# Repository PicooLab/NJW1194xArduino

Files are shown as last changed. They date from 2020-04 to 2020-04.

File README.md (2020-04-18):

# NJW1194 x Arduino

2-Channel Electronic Volume With Input Selector And Tone Control

Designed with Kicad and Arduino IDE;

## Related

+ NJW1194
  <https://www.njr.com/semicon/products/NJW1194.html>
  [Datasheet](assets/NJW1194_E.pdf)
+ Arduino Nano
  <https://store.arduino.cc/usa/arduino-nano>
+ 1602_I2C Screen
  <https://github.com/mathertel/LiquidCrystal_PCF8574>
+ EC11 Ratary Encoder
  <https://tech.alpsalpine.com/prod/e/html/encoder/incremental/ec11/ec11_list.html>

## Hardware

### 1. NJW1194 board

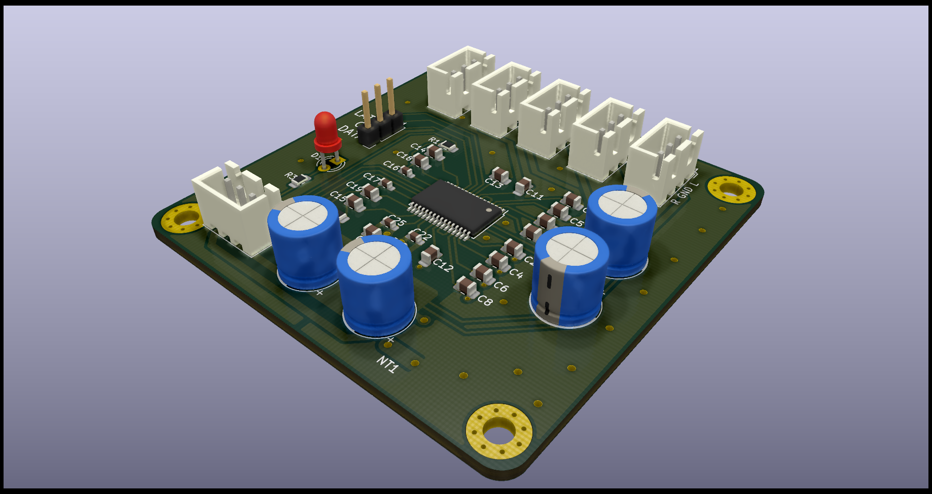
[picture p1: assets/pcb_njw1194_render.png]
NJW1194


Size : 60mmx60mm

### 2. POWER board

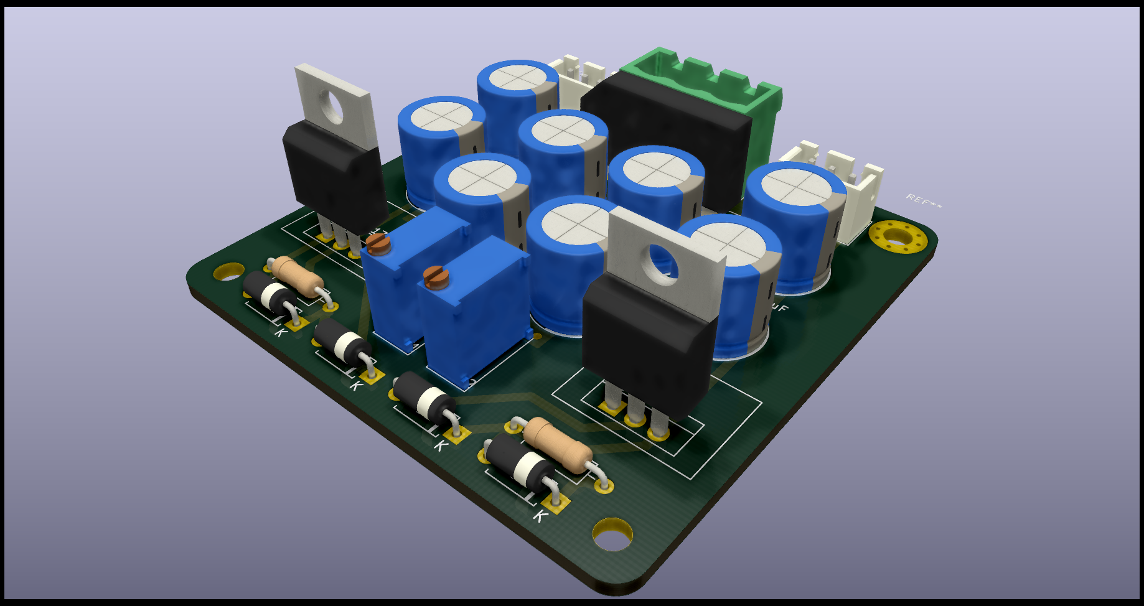
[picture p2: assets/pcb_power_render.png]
POWER


Size : 60mmx60mm

### 3. CONTROL board

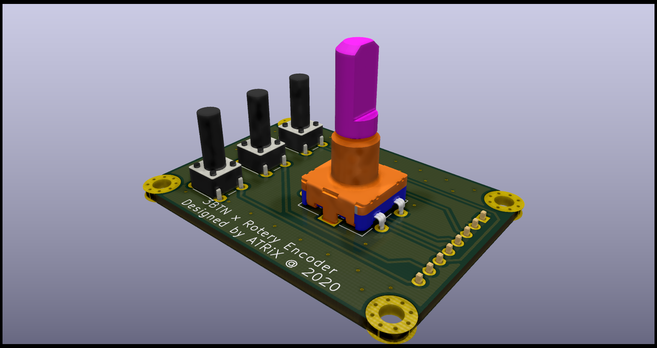
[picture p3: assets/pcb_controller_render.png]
CONTROL


Size : 36mmx50mm

## Software

[Arduino nano](nano_eeprom_bal/nano_eeprom_bal.ino)

not elegant enough yet

## Assemble

TBD...

## MIT License

Copyright (c) 2020 ATRiiX

Permission is hereby granted, free of charge, to any person obtaining a copy
of this software and associated documentation files (the "Software"), to deal
in the Software without restriction, including without limitation the rights
to use, copy, modify, merge, publish, distribute, sublicense, and/or sell
copies of the Software, and to permit persons to whom the Software is
furnished to do so, subject to the following conditions:

The above copyright notice and this permission notice shall be included in all
copies or substantial portions of the Software.

THE SOFTWARE IS PROVIDED "AS IS", WITHOUT WARRANTY OF ANY KIND, EXPRESS OR
IMPLIED, INCLUDING BUT NOT LIMITED TO THE WARRANTIES OF MERCHANTABILITY,
FITNESS FOR A PARTICULAR PURPOSE AND NONINFRINGEMENT. IN NO EVENT SHALL THE
AUTHORS OR COPYRIGHT HOLDERS BE LIABLE FOR ANY CLAIM, DAMAGES OR OTHER
LIABILITY, WHETHER IN AN ACTION OF CONTRACT, TORT OR OTHERWISE, ARISING FROM,
OUT OF OR IN CONNECTION WITH THE SOFTWARE OR THE USE OR OTHER DEALINGS IN THE
SOFTWARE.

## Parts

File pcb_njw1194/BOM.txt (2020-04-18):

BOM of NJW1194

J1;                   PinHeader_P2.54mm_3P;   1;
J2-J7;                JST_XH2.54mm_3P;        6;

U1;                   SSOP-32;                1;    NJW1194;

R1,R2;                R_0805;                 2;    4.7K;
R3;                   R_0805;                 1;    1k-1.5k;
D1;                   LED_D3.0mm;             1;

C9,C10,C20,C23;       CP_D8mm_P3.5mm;         2;    100uF;
C16,C17,C22,C25;      C_0603";                4;    100nf;
C1-C8,C11-13,C21,C24; C_0805";               13;    10uf;
C14,C15;              C_0805";                2;    3.3nf;
C18,C19;              C_0805";                2;    4.7uf;

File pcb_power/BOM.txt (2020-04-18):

BOM of LM317x337

J1;                  "5.08mm_3P";        1;
J2,J3;               "XH2.54_3P";        2;

U1;                  "TO-220";           1;    LM317;
U2;                  "TO-220";           1;    LM337;

R1,R2;               "R1/4W";            2;    100;
RV2,RV1;             "3296W";            2;    1K;
D1";                 "Diode_Bridge";     1;    D_Bridge_+AA-;
D2-D5;               "4N7001";           4;

C14,C13,C8,C7,C1-C4; "CP_D10mm_P5mm";    8;    1000u;
C12,C11,C6,C5;       "C_0603;            4;    100nf
C10,C9;              "C_0805";           2;    10uf;

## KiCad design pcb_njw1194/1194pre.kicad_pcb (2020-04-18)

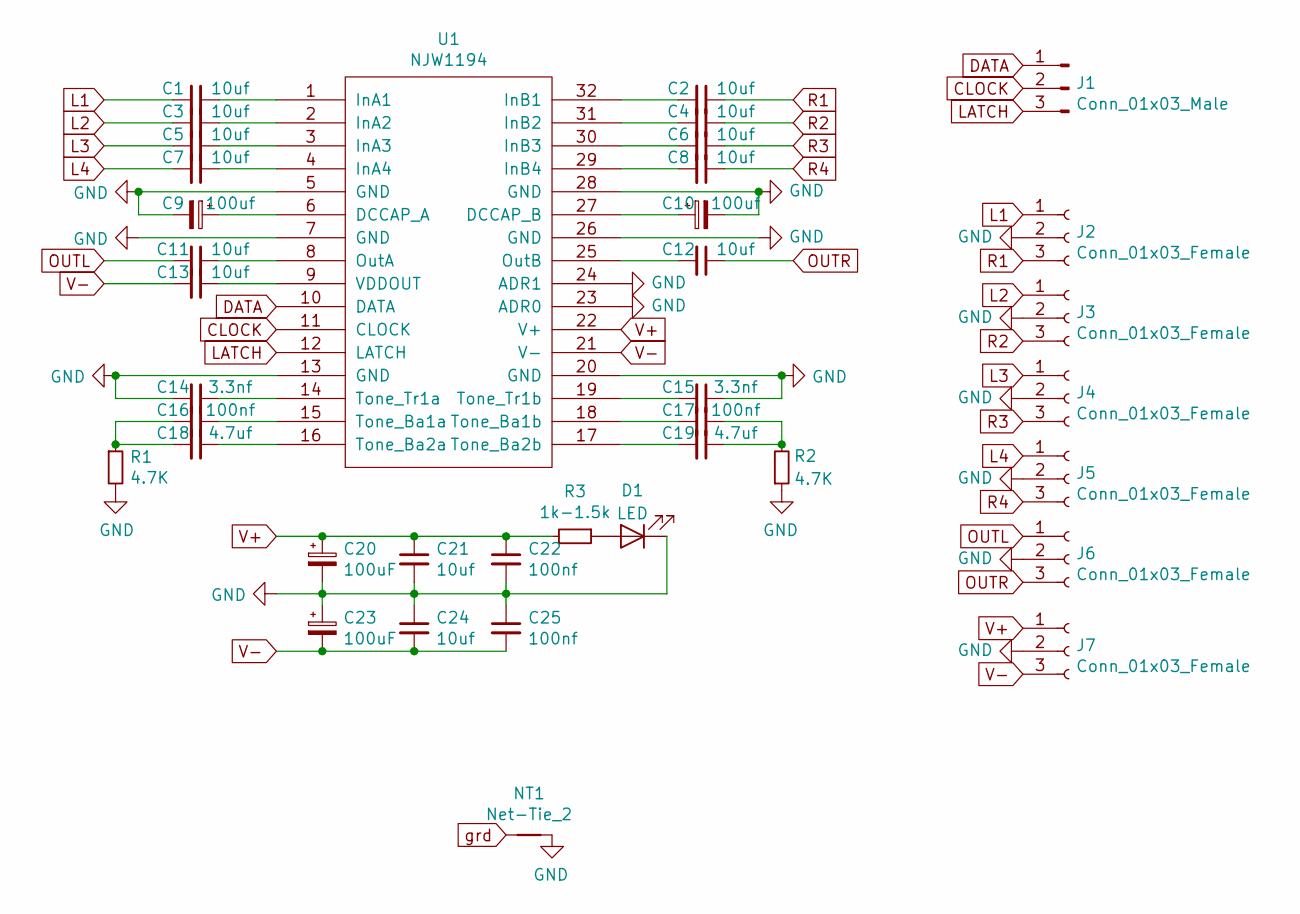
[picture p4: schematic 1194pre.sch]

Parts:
C1, C2, C3, C4, C5, C6, C7, C8, C11, C12, C13, C21, C24: 10uf; C_0805_2012Metric_Pad1.15x1.40mm_HandSolder
C9, C10: 100uf; CP_Radial_D8.0mm_P3.50mm
C14, C15: 3.3nf; C_0805_2012Metric_Pad1.15x1.40mm_HandSolder
C16, C17, C22, C25: 100nf; C_0603_1608Metric_Pad1.05x0.95mm_HandSolder
C18, C19: 4.7uf; C_0805_2012Metric_Pad1.15x1.40mm_HandSolder
C20, C23: 100uF; CP_Radial_D8.0mm_P3.50mm
D1: LED; LED_D3.0mm
J1: Conn_01x03_Male; PinHeader_1x03_P2.54mm_Vertical
J2, J3, J4, J5, J6, J7: Conn_01x03_Female; JST_XH_B3B-XH-A_1x03_P2.50mm_Vertical
NT1: Net-Tie_2; NetTie-2_SMD_Pad2.0mm
R1, R2: 4.7K; R_0805_2012Metric_Pad1.15x1.40mm_HandSolder
R3: 1k-1.5k; R_0805_2012Metric_Pad1.15x1.40mm_HandSolder
U1: NJW1194; TSSOP-32_6.1x11mm_P0.65mm

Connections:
CLOCK: J1.2, U1.11 (CLOCK)
DATA: J1.1, U1.10 (DATA)
GND: C9.2, C10.2, C14.2, C15.1, C20.2, C21.2, C22.2, C23.1, C24.1, C25.1, D1.1 (K), J2.2, J3.2, J4.2, J5.2, J6.2, J7.2, NT1.2, R1.2, R2.1, U1.5 (GND), U1.7 (GND), U1.13 (GND), U1.20 (GND), U1.23 (ADR0), U1.24 (ADR1), U1.26 (GND), U1.28 (GND)
L1: C1.2, J2.1
L2: C3.2, J3.1
L3: C5.2, J4.1
L4: C7.2, J5.1
LATCH: J1.3, U1.12 (LATCH)
unnamed: C1.1, U1.1 (InA1)
unnamed: C2.2, U1.32 (InB1)
unnamed: C3.1, U1.2 (InA2)
unnamed: C4.2, U1.31 (InB2)
unnamed: C5.1, U1.3 (InA3)
unnamed: C6.2, U1.30 (InB3)
unnamed: C7.1, U1.4 (InA4)
unnamed: C8.2, U1.29 (InB4)
unnamed: C9.1, U1.6 (DCCAP_A)
unnamed: C10.1, U1.27 (DCCAP_B)
unnamed: C11.1, U1.8 (OutA)
unnamed: C12.2, U1.25 (OutB)
unnamed: C13.1, U1.9 (VDDOUT)
unnamed: C14.1, U1.14 (Tone_Tr1a)
unnamed: C15.2, U1.19 (Tone_Tr1b)
unnamed: C16.1, U1.15 (Tone_Ba1a)
unnamed: C16.2, C18.2, R1.1
unnamed: C17.1, C19.1, R2.2
unnamed: C17.2, U1.18 (Tone_Ba1b)
unnamed: C18.1, U1.16 (Tone_Ba2a)
unnamed: C19.2, U1.17 (Tone_Ba2b)
unnamed: D1.2 (A), R3.1
OUTL: C11.2, J6.1
OUTR: C12.1, J6.3
R1: C2.1, J2.3
R2: C4.1, J3.3
R3: C6.1, J4.3
R4: C8.1, J5.3
V+: C20.1, C21.1, C22.1, J7.1, R3.2, U1.22 (V+)
V-: C13.2, C23.2, C24.2, C25.2, J7.3, U1.21 (V-)
grd: NT1.1

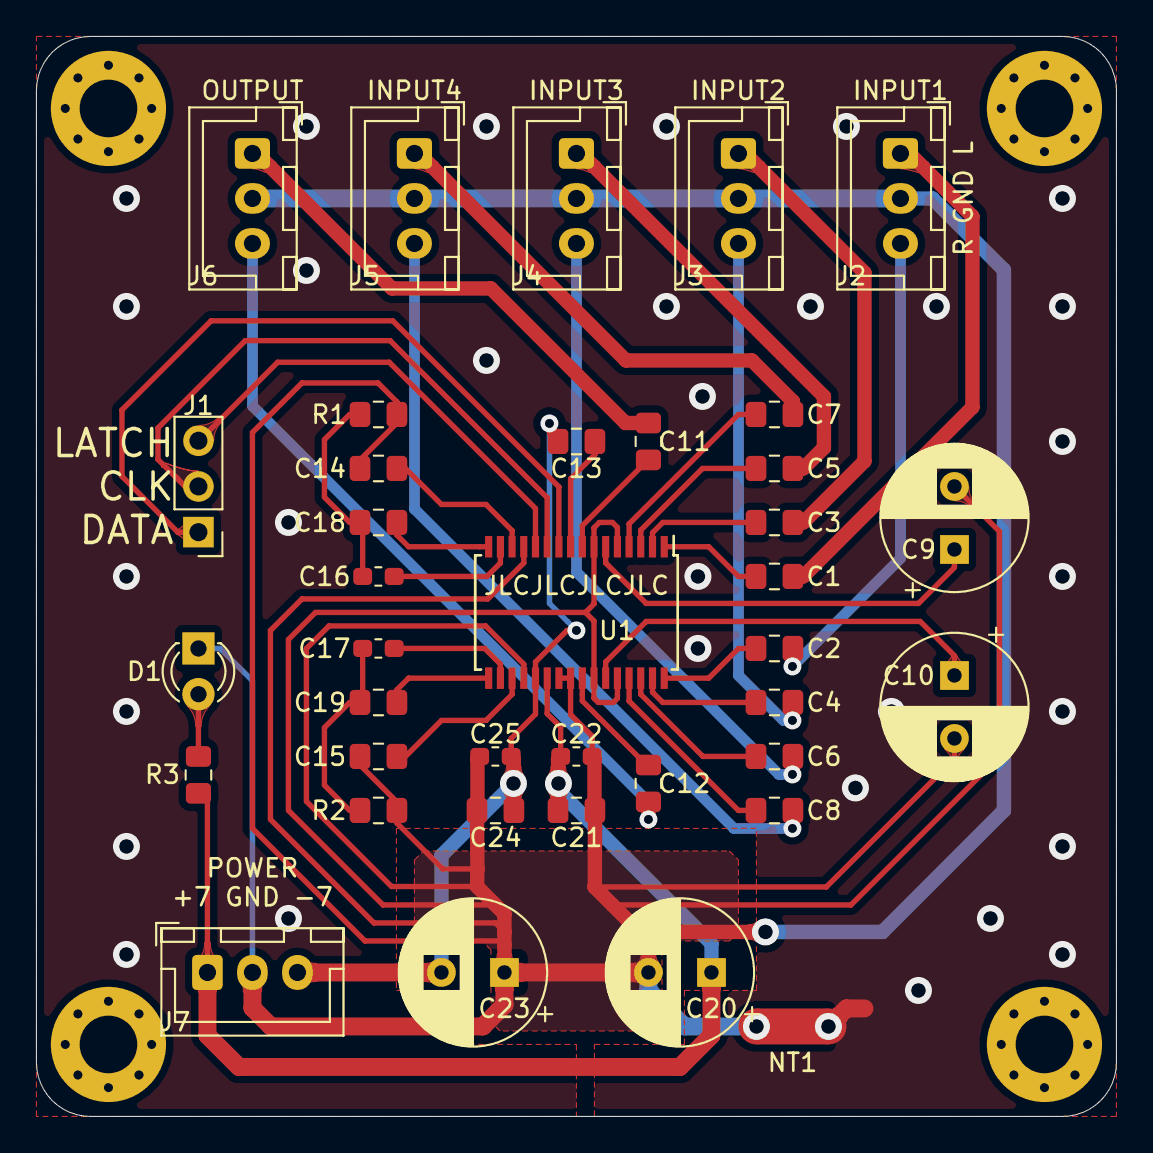
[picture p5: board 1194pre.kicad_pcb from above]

Board: 2 copper layers, 60.0 x 60.0 mm, 38 parts (0 on the bottom side), 38 nets.

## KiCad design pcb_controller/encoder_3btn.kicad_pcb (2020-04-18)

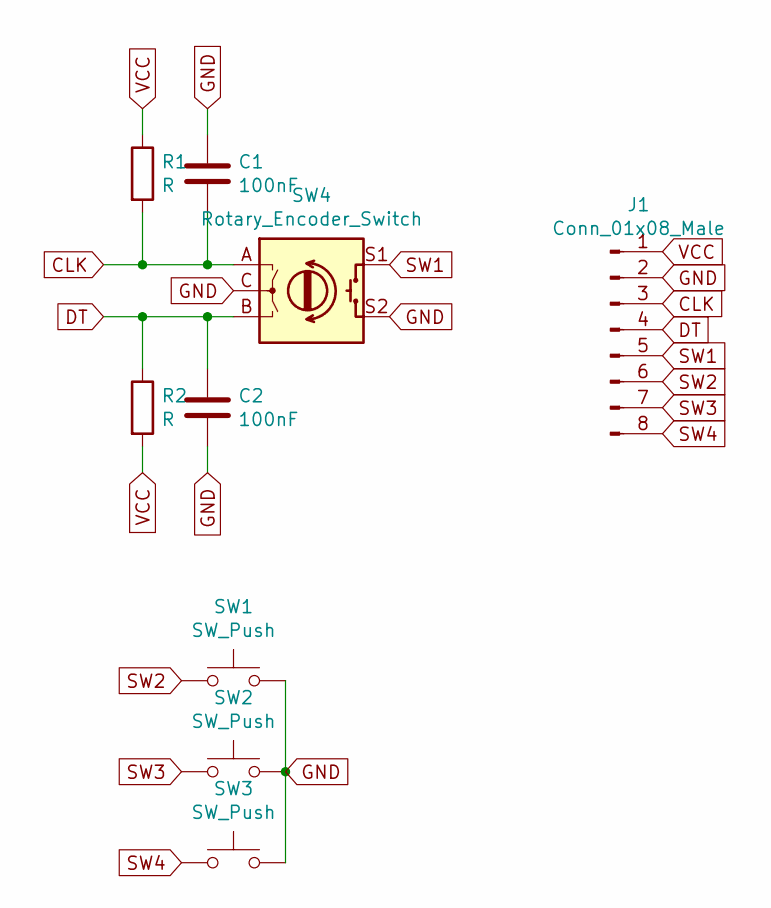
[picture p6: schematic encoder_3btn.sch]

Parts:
C1, C2: 100nF; C_0603_1608Metric_Pad1.05x0.95mm_HandSolder
J1: Conn_01x08_Male; PinHeader_1x08_P2.54mm_Horizontal
R1, R2: R; R_0805_2012Metric_Pad1.15x1.40mm_HandSolder
SW1, SW2, SW3: SW_Push; SW_PUSH_6mm_H13mm
SW4: Rotary_Encoder_Switch; RotaryEncoder_Alps_EC11E-Switch_Vertical_H20mm

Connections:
CLK: C1.2, J1.3, R1.2, SW4.A
DT: C2.1, J1.4, R2.1, SW4.B
GND: C1.1, C2.2, J1.2, SW1.2, SW2.2, SW3.2, SW4.C, SW4.S2
SW1: J1.5, SW4.S1
SW2: J1.6, SW1.1
SW3: J1.7, SW2.1
SW4: J1.8, SW3.1
VCC: J1.1, R1.1, R2.2

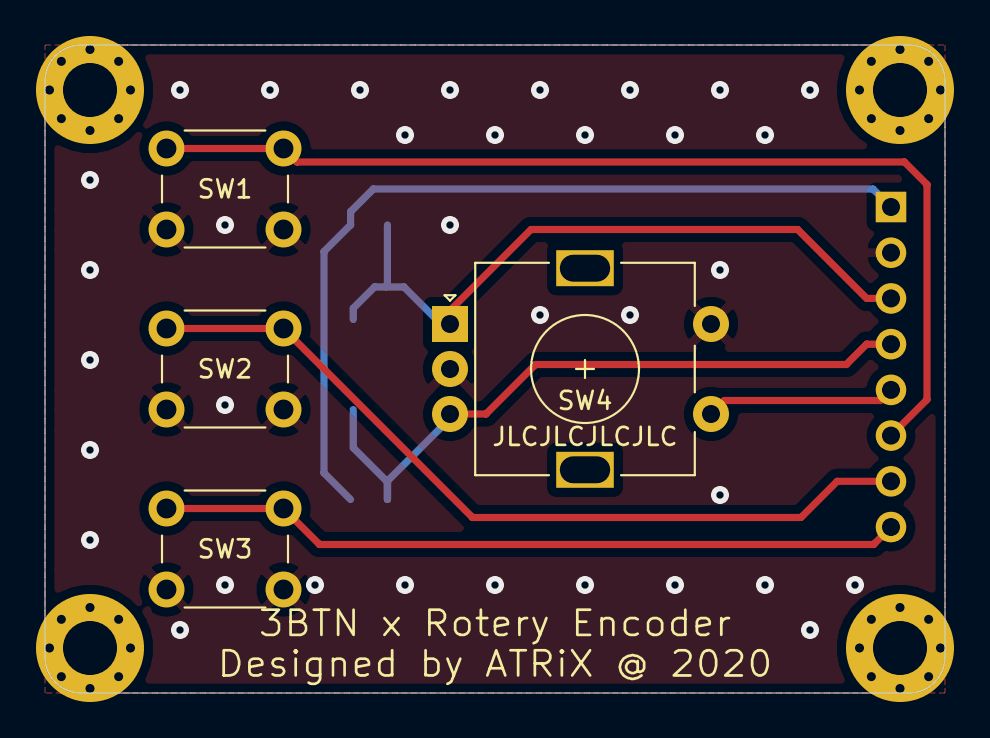
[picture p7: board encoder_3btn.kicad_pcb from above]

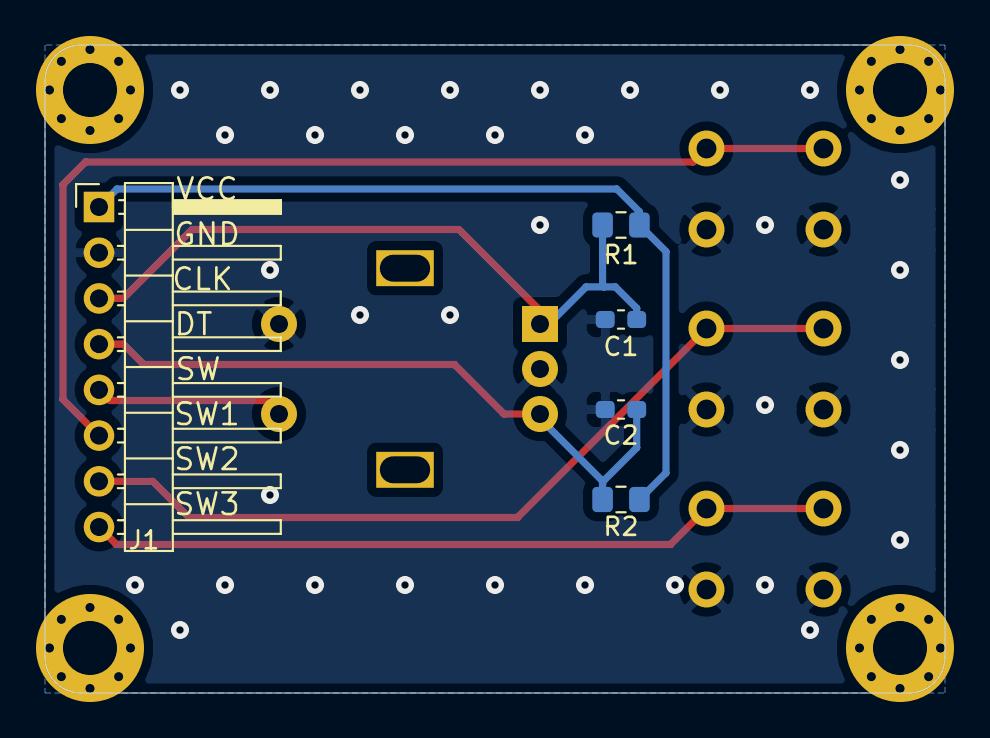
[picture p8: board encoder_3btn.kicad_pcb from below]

Board: 2 copper layers, 50.0 x 36.0 mm, 13 parts (5 on the bottom side), 8 nets.

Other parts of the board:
REF1, REF2, REF3, REF4: MountingHole_3mm_Pad_Via

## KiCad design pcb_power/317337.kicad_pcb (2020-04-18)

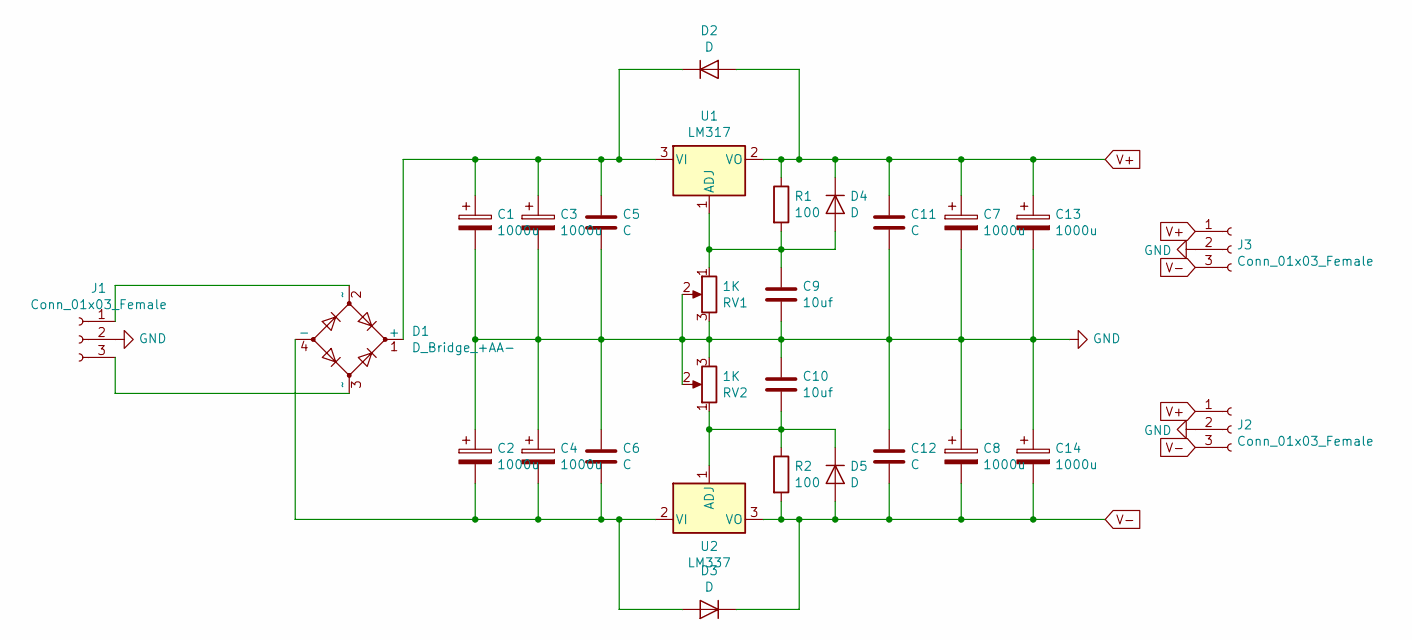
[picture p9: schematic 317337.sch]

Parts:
C1, C2, C3, C4, C7, C8, C13, C14: 1000u; CP_Radial_D10.0mm_P5.00mm
C5, C6, C11, C12: C; C_0603_1608Metric_Pad1.05x0.95mm_HandSolder
C9, C10: 10uf; C_0805_2012Metric_Pad1.15x1.40mm_HandSolder
D1: D_Bridge_+AA-; Diode_Bridge_Vishay_GBL
D2, D3, D4, D5: D; D_A-405_P7.62mm_Horizontal
J1: Conn_01x03_Female; PhoenixContact_MSTBVA_2,5_3-G-5,08_1x03_P5.08mm_Vertical
J2, J3: Conn_01x03_Female; JST_XH_B3B-XH-A_1x03_P2.50mm_Vertical
R1, R2: 100; R_Axial_DIN0207_L6.3mm_D2.5mm_P10.16mm_Horizontal
RV1, RV2: 1K; Potentiometer_Bourns_3296W_Vertical
U1: LM317; TO-220-3_Vertical
U2: LM337; TO-220-3_Vertical

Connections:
GND: C1.2, C2.1, C3.2, C4.1, C5.2, C6.1, C7.2, C8.1, C9.2, C10.1, C11.2, C12.1, C13.2, C14.1, J1.2, J2.2, J3.2, RV1.2, RV1.3, RV2.2, RV2.3
unnamed: C1.1, C3.1, C5.1, D1.1 (+), D2.1 (K), U1.3 (VI)
unnamed: C2.2, C4.2, C6.2, D1.4 (-), D3.2 (A), U2.2 (VI)
unnamed: C9.1, D4.2 (A), R1.2, RV1.1, U1.1 (ADJ)
unnamed: C10.2, D5.1 (K), R2.1, RV2.1, U2.1 (ADJ)
unnamed: D1.2 (~~), J1.1
unnamed: D1.3 (~~), J1.3
V+: C7.1, C11.1, C13.1, D2.2 (A), D4.1 (K), J2.1, J3.1, R1.1, U1.2 (VO)
V-: C8.2, C12.2, C14.2, D3.1 (K), D5.2 (A), J2.3, J3.3, R2.2, U2.3 (VO)

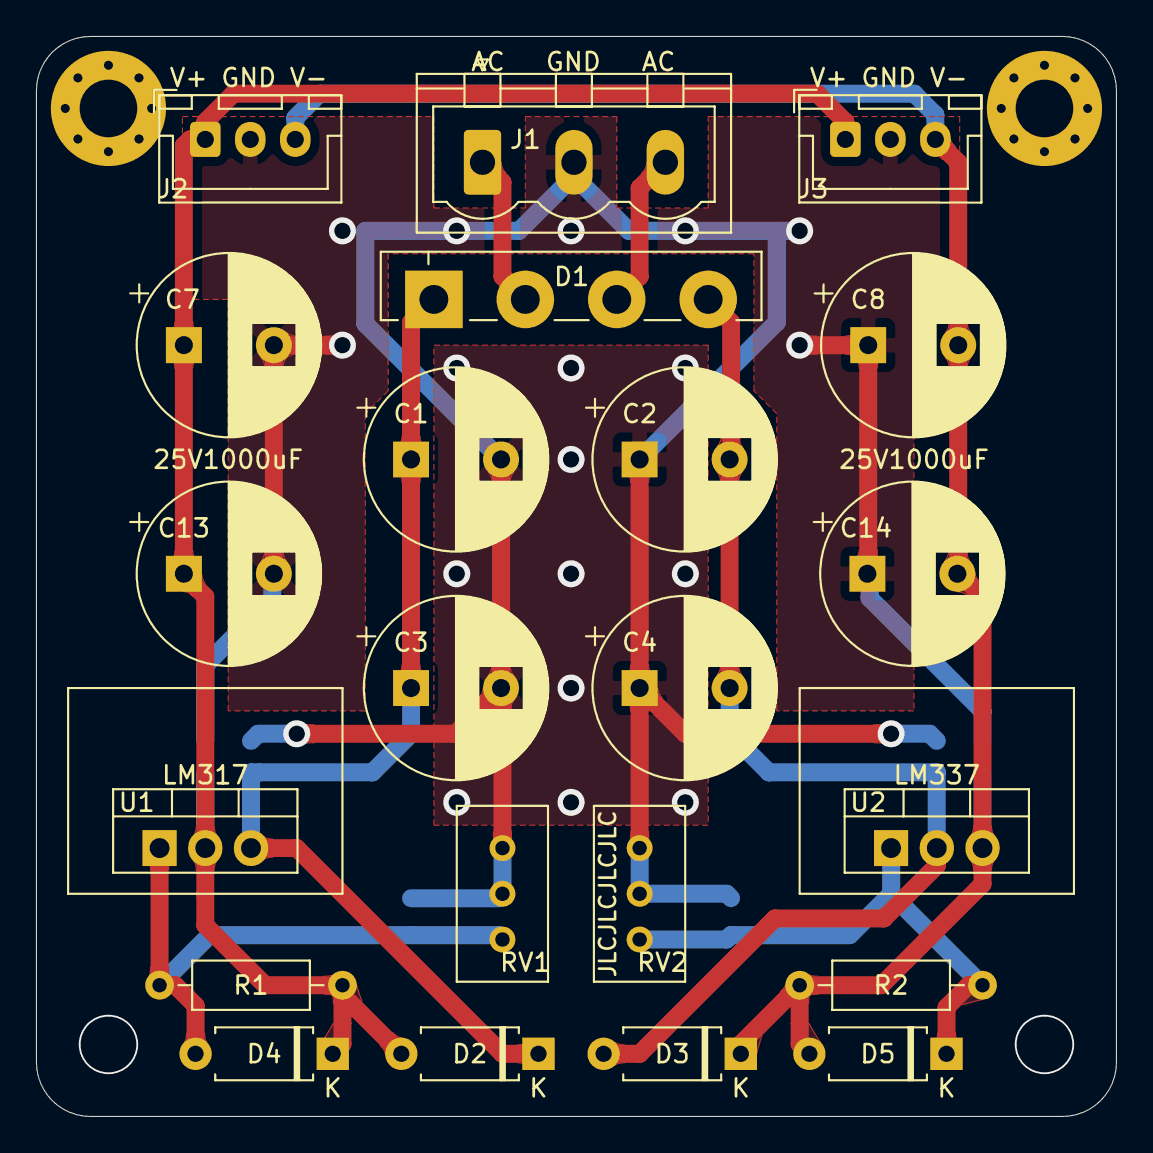
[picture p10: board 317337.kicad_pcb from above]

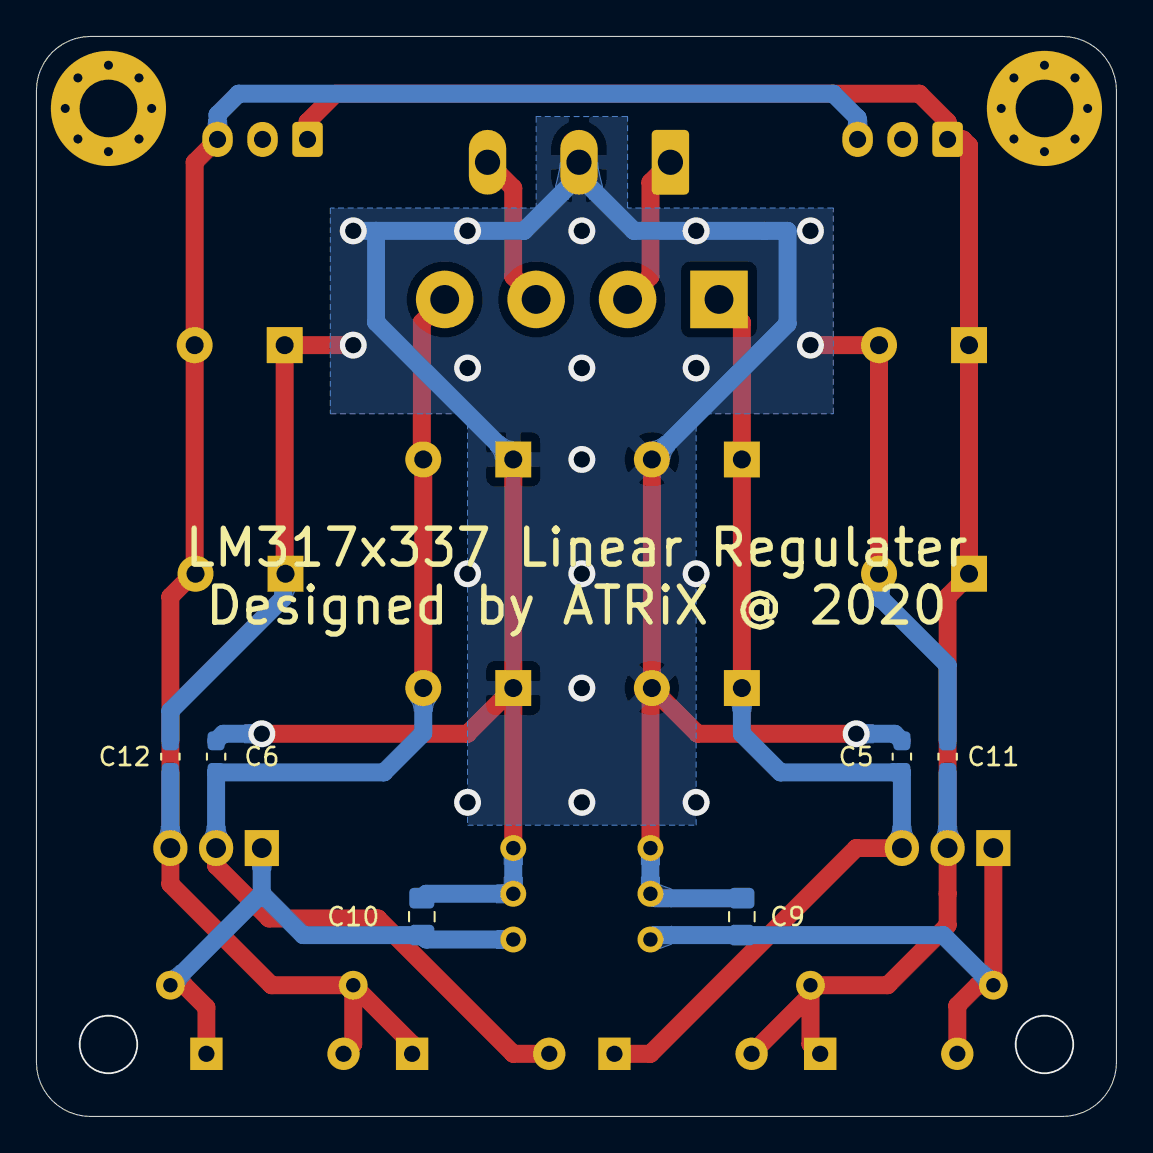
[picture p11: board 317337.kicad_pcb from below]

Board: 2 copper layers, 60.0 x 60.0 mm, 28 parts (6 on the bottom side), 9 nets.

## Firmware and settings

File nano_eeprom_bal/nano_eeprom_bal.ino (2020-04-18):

#include <LiquidCrystal_PCF8574.h>
#include <EEPROM.h>
#include <Wire.h>

LiquidCrystal_PCF8574 lcd(0x27); // set the LCD address to 0x27 for a 16 chars and 2 line display

//NANO EEPROM
//each byte hold a value from 0 to 255
#define EEPROM_CHANNEL 0 //1 to 4
#define EEPROM_MUTE 1    //0 or 1
#define EEPROM_VOLUME 2  //1 to 254  <-> 31.5dB to -95dB,default = 64
#define EEPROM_BALANCE 3 //0 to 80   <-> -20dB to 20dB,  default = 40
#define EEPROM_BYPASS 4  //0 or 1
#define EEPROM_TREBLE 5  //0 to 20   <-> -10dB to 10dB,  default = 10
#define EEPROM_BASS 6    //0 to 20   <-> -10dB to 10dB

//NANO GPIO
//pin keys
#define PIN_CHANNEL 9
#define PIN_MUTE 8
#define PIN_UP 7
#define PIN_DOWN 6
#define PIN_SELECT 5 //Volume,Treble,Bass,Balance
#define PIN_BYPASS 4
//pin njw1194
#define PIN_LATCH A1
#define PIN_CLK A2
#define PIN_DATA A3
//pin rotary encoder
#define PIN_CLK2 10
#define PIN_DT 11

//
#define PINBTN(pinname)    \
  pinMode(pinname, INPUT); \
  digitalWrite(pinname, HIGH);

//
#define BTN_EVENT(pinname, pinx, event, longpush)               \
  static boolean lock_##pinname = false;                        \
  static int count_##pinname = 0;                               \
  if (digitalRead(pinx) == LOW && lock_##pinname == false)      \
  {                                                             \
    lock_##pinname = true;                                      \
    count_##pinname = 0;                                        \
    event();                                                    \
    evt_btn_common();                                           \
  }                                                             \
  else if (digitalRead(pinx) == HIGH && lock_##pinname == true) \
  {                                                             \
    lock_##pinname = false;                                     \
  }                                                             \
  else if (digitalRead(pinx) == LOW && longpush)                \
  {                                                             \
    if (count_##pinname < 500)                                  \
      count_##pinname++;                                        \
    else                                                        \
    {                                                           \
      event();                                                  \
      evt_btn_common();                                         \
    }                                                           \
  }

//
struct Config
{
  byte channel, mute, volume, balance, bypass, treble, bass;
};

Config myConfig = {0, 1, 64, 40, 0, 10, 10};

byte select = 0; //0:Vol,1:Tre,2:Bass,3:Bal;

void evt_btn_ch()
{
  myConfig.channel = (myConfig.channel + 1) % 4;
}
void evt_btn_mu()
{
  if (myConfig.mute == 0)
  {
    myConfig.mute = 1;
  }
  else
  {
    myConfig.mute = 0;
  }
}
void evt_btn_vu()
{
  switch (select)
  {
  case 0:
    if (myConfig.volume >= 4 && myConfig.volume <= 32)
      myConfig.volume -= 2; //16 to 31
    if (myConfig.volume >= 33 && myConfig.volume <= 96)
      myConfig.volume--; //-16 to 16  step 0.5db
    if (myConfig.volume >= 98 && myConfig.volume <= 128)
      myConfig.volume -= 2; //-32 to -16 step 1db
    if (myConfig.volume > 128)
      myConfig.volume -= 8;
    break;

  case 1:
    if (myConfig.treble < 20)
      myConfig.treble++;
    break;

  case 2:
    if (myConfig.bass < 20)
      myConfig.bass++;
    break;

  case 3:
    if (myConfig.balance < 80)
      myConfig.balance++;
    break;

  default:
    break;
  }
}
void evt_btn_vd()
{
  switch (select)
  {
  case 0:
    if (myConfig.volume >= 128 && myConfig.volume < 248)
      myConfig.volume += 8;
    if (myConfig.volume >= 96 && myConfig.volume < 128)
      myConfig.volume += 2; //-32 to -16 step 1db
    if (myConfig.volume >= 32 && myConfig.volume < 96)
      myConfig.volume++; //-16 to 16  step 0.5db
    if (myConfig.volume >= 2 && myConfig.volume < 32)
      myConfig.volume += 2; //16 to 31
    break;

  case 1:
    if (myConfig.treble > 0)
      myConfig.treble--;
    break;

  case 2:
    if (myConfig.bass > 0)
      myConfig.bass--;
    break;

  case 3:
    if (myConfig.balance > 0)
      myConfig.balance--;
    break;

  default:
    break;
  }
}
void evt_btn_sl()
{
  select = (select + 1) % 4; //4 modes;
}
void evt_btn_bp()
{
  if (myConfig.bypass == 0)
  {
    myConfig.bypass = 1;
  }
  else
  {
    myConfig.bypass = 0;
  }
}

void evt_btn_common()
{
  //serial print
  Serial.println("==============================");
  Serial.print("Current Select:");
  switch (select)
  {
  case 0:
    Serial.println("VOL");
    break;
  case 1:
    Serial.println("TRE");
    break;
  case 2:
    Serial.println("BAS");
    break;
  case 3:
    Serial.println("BAL");
    break;
  default:
    break;
  }
  Serial.print("Ch: ");
  Serial.print(myConfig.channel);
  Serial.print(", Mute: ");
  Serial.print(myConfig.mute);
  Serial.print(", Vol: ");
  Serial.print((64 - myConfig.volume) / 2.0);
  Serial.println("dB.");
  Serial.print("Bal: ");
  Serial.print((myConfig.balance - 40) / 2.0);
  Serial.println("dB.");
  Serial.print("Bypass: ");
  Serial.print(myConfig.bypass);
  Serial.print(" Treble: ");
  Serial.print((myConfig.treble - 10));
  Serial.print("dB. ");
  Serial.print(" Bass: ");
  Serial.print((myConfig.bass - 10));
  Serial.println("dB. ");

  //lcd print
  lcd.setCursor(2, 0);
  lcd.print(myConfig.channel);
  lcd.setCursor(8, 0);
  lcd.print(myConfig.mute);
  lcd.setCursor(14, 0);
  lcd.print(myConfig.bypass);
  lcd.setCursor(1, 1);
  switch (select)
  {
  case 0:
    lcd.print("VOL :       dB");
    lcd.setCursor(7, 1);
    if ((64 - myConfig.volume) / 2.0 > -16)
    {
      lcd.print((64 - myConfig.volume) / 2.0, 1);
    }
    else
    {
      lcd.print((64 - myConfig.volume) / 2.0, 0);
    }
    break;
  case 1:
    lcd.print("TREB :      dB");
    lcd.setCursor(8, 1);
    lcd.print(myConfig.treble - 10);
    break;
  case 2:
    lcd.print("BASS :      dB");
    lcd.setCursor(8, 1);
    lcd.print(myConfig.bass - 10);
    break;
  case 3:
    lcd.print("BAL :       dB");
    lcd.setCursor(7, 1);
    lcd.print((myConfig.balance - 40) / 2.0, 1);
    break;
  default:
    break;
  }

  //send to njw
  if (myConfig.mute == 0)
  {

    sendVol();
    sendSelect();
    if (myConfig.bypass == 0)
    {
      sendTre();
      sendBass();
    }
    else
    {
      sendBypass();
    }
  }
  else
  {
    sendMute();
  }
}

//encoder type1
void encoderEvent()
{
  byte clkValue = digitalRead(PIN_CLK2); //读取CLK引脚的电平
  byte dtValue = digitalRead(PIN_DT);    //读取DT引脚的电平
  static byte lastCLK = 1;
  if (lastCLK != clkValue)
  {
    lastCLK = clkValue;
    if (clkValue != dtValue)
    {
      evt_btn_vu();
    }
    else
    {
      evt_btn_vd();
    }
    evt_btn_common();
    Serial.print(clkValue != dtValue ? '+' : '-');
  }
}

//encoder type2
void encoderEvent2()
{
  static boolean b = true;               //一个step
  byte clkValue = digitalRead(PIN_CLK2); //读取CLK引脚的电平
  byte dtValue = digitalRead(PIN_DT);    //读取DT引脚的电平
  if (b && clkValue == 0 && dtValue == 1)
  {
    evt_btn_vu();
    b = false;
    Serial.print('+');
  }
  if (b && clkValue == 1 && dtValue == 0)
  {
    evt_btn_vd();
    b = false;
    Serial.print('-');
  }
  if (!b && clkValue == 1 && dtValue == 1)
  {
    b = true;
    evt_btn_common();
  }
}

void updateROM()
{
  EEPROM.update(EEPROM_CHANNEL, myConfig.channel);
  EEPROM.update(EEPROM_MUTE, myConfig.mute);
  EEPROM.update(EEPROM_VOLUME, myConfig.volume);
  EEPROM.update(EEPROM_BALANCE, myConfig.balance);
  EEPROM.update(EEPROM_BYPASS, myConfig.bypass);
  EEPROM.update(EEPROM_TREBLE, myConfig.treble);
  EEPROM.update(EEPROM_BASS, myConfig.bass);

  Serial.println("ROM saved!");
}

void sendRaw(byte data, byte add)
{
  digitalWrite(PIN_LATCH, LOW); //LATCH
  //15-8
  for (byte i = 8; i >= 1; i--)
  {
    digitalWrite(PIN_CLK, HIGH);
    digitalWrite(PIN_DATA, (data >> (i - 1)) % 2);
    Serial.print((data >> (i - 1)) % 2);
    delay(0.01);
    digitalWrite(PIN_CLK, LOW);
    delay(0.01);
  }
  Serial.print("|");
  //7-4
  for (byte i = 4; i >= 1; i--)
  {
    digitalWrite(PIN_CLK, HIGH);
    digitalWrite(PIN_DATA, (add >> (i - 1)) % 2);
    Serial.print((add >> (i - 1)) % 2);
    delay(0.01);
    digitalWrite(PIN_CLK, LOW);
    delay(0.01);
  }
  Serial.print("|");
  //3-0
  for (byte i = 4; i >= 1; i--)
  {
    digitalWrite(PIN_CLK, HIGH);
    digitalWrite(PIN_DATA, LOW);
    Serial.print(0);
    delay(0.01);
    digitalWrite(PIN_CLK, LOW);
    delay(0.01);
  }
  //empty
  digitalWrite(PIN_LATCH, HIGH);
  digitalWrite(PIN_CLK, HIGH);
  digitalWrite(PIN_DATA, LOW);
  delay(0.01);
  Serial.println();
}

void sendVol()
{
  if (myConfig.balance == 40 || myConfig.volume >= 208)
  {
    sendRaw(myConfig.volume, 0);
    sendRaw(myConfig.volume, 1);
  }
  else if (myConfig.balance > 40)
  {
    sendRaw(myConfig.volume + (myConfig.balance - 40), 0);
    sendRaw(myConfig.volume, 1);
  }
  else if (myConfig.balance < 40)
  {
    sendRaw(myConfig.volume, 0);
    sendRaw(myConfig.volume + (40 - myConfig.balance), 1);
  }
}
void sendMute()
{
  sendRaw(255, 0);
  sendRaw(255, 1);
  sendRaw(0, 2);
}
void sendSelect()
{
  sendRaw((myConfig.channel + 1) << 2, 2);
}
void sendTre()
{
  byte tmp = 0;
  if (myConfig.treble > 10)
    tmp = (1 << 7) | ((myConfig.treble - 10) << 3) | 1 << 2;
  else
    tmp = (0 << 7) | ((10 - myConfig.treble) << 3) | 1 << 2;
  sendRaw(tmp, 3);
}
void sendBass()
{
  byte tmp = 0;
  if (myConfig.bass > 10)
    tmp = (1 << 7) | ((myConfig.bass - 10) << 3) | 1 << 2;
  else
    tmp = (0 << 7) | ((10 - myConfig.bass) << 3) | 1 << 2;
  sendRaw(tmp, 4);
}
void sendBypass()
{
  sendRaw(0, 3);
}

void setup()
{
  //serial
  Serial.begin(115200);
  Serial.println("Hello!");
  //lcd
  lcd.begin(16, 2);
  lcd.setBacklight(0);
  lcd.clear();
  delay(500);

  //hello
  lcd.setBacklight(1);
  lcd.home();
  lcd.setCursor(1, 0);
  lcd.print("NJW1194 Volume");
  lcd.setCursor(3, 1);
  lcd.print("Controller");
  delay(500);

  //pin init
  PINBTN(PIN_CHANNEL);
  PINBTN(PIN_MUTE);
  PINBTN(PIN_UP);
  PINBTN(PIN_DOWN);
  PINBTN(PIN_SELECT);
  PINBTN(PIN_BYPASS);
  pinMode(PIN_CLK2, INPUT);
  //digitalWrite(PIN_CLK2, HIGH);
  pinMode(PIN_DT, INPUT);
  //digitalWrite(PIN_DT, HIGH);

  //3-wire njw
  pinMode(PIN_LATCH, OUTPUT);
  digitalWrite(PIN_LATCH, HIGH);
  pinMode(PIN_CLK, OUTPUT);
  digitalWrite(PIN_CLK, HIGH);
  pinMode(PIN_DATA, OUTPUT);
  digitalWrite(PIN_DATA, HIGH);

  if (digitalRead(PIN_CHANNEL) == LOW)
  {
    //reset config
    updateROM();
    Serial.print("RESETED!");
    lcd.clear();
    lcd.setCursor(2, 1);
    lcd.print("RESET CONFIG");
  }
  else
  {
    //load config from eeprom
    myConfig.channel = EEPROM.read(EEPROM_CHANNEL);
    myConfig.mute = EEPROM.read(EEPROM_MUTE);
    myConfig.volume = EEPROM.read(EEPROM_VOLUME);
    myConfig.balance = EEPROM.read(EEPROM_BALANCE);
    myConfig.bypass = EEPROM.read(EEPROM_BYPASS);
    myConfig.treble = EEPROM.read(EEPROM_TREBLE);
    myConfig.bass = EEPROM.read(EEPROM_BASS);
    Serial.println("ROM LOADED!");
    lcd.clear();
    lcd.setCursor(2, 1);
    lcd.print("LOAD CONFIG");
  }
  delay(1000);
  lcd.clear();
  lcd.print("CH  MUTE  PASS");

  evt_btn_common();
}

void loop()
{
  //btn scan
  BTN_EVENT(channel, PIN_CHANNEL, evt_btn_ch, false);
  BTN_EVENT(mute, PIN_MUTE, evt_btn_mu, false);
  BTN_EVENT(up, PIN_UP, evt_btn_vu, true);
  BTN_EVENT(down, PIN_DOWN, evt_btn_vd, true);
  BTN_EVENT(select, PIN_SELECT, evt_btn_sl, false);
  BTN_EVENT(bypass, PIN_BYPASS, evt_btn_bp, false);
  //encoder
  encoderEvent2();

  //save
  delay(1);
  static int count_eeprom = 0;
  count_eeprom++;
  if (count_eeprom == 20000)
  {
    count_eeprom = 0;
    updateROM();
    //save eeprom every 20s
  }
}
